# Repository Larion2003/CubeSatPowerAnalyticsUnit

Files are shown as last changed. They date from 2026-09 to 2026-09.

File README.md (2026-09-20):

# TiSAT CubeSat - Power Analytics Unit 
 
This repository contains the design and development files for the Power Analytics Unit of the **TiSAT CubeSat** project. The primary objective is to monitor and analyze the power consumption of various sensors integrated into the satellite. 
 
## Project Overview 
The core of this project is a custom-designed power measurement circuit. It utilizes a **shunt resistor** to measure minute currents and voltage levels across specific circuit branches, enabling precise power calculation.  
 
Since the satellite is equipped with **solar panels** for battery charging, the power management logic accounts for both energy harvesting and consumption cycles to ensure balanced power distribution. 
 
## Current Progress
- [x] **Circuit Design:** Completed the schematic and PCB layout using **KiCad**.
- [x] **Component Selection:** Selected specialized ICs for precision current sensing and power management.
- [x] **Manufacturing & Assembly:** The custom PCB has been fully manufactured, and all SMD and through-hole components (including critical high-precision IC packages) have been successfully soldered and assembled.
- [x] **Firmware Communication Loop:** Successfully established a low-level, non-blocking hardware communication interface between the STM32 MCU and a Raspberry Pi Pico W using UART with inverted polarity.
- [x] **Ping-Pong Verification:** Confirmed working end-to-end UART communication on the shared single-wire bus — the STM32 now reliably replies `pong\n` to every `ping\n` sent by the Raspberry Pi Pico W, verifying the physical link between the two microcontrollers.
- [x] **Shunt Resistor Calibration:** Performed a 4-point (Kelvin) measurement to precisely determine the shunt resistor's true value (50 mΩ).
- [x] **TiSAT Protocol Implementation:** Replaced the raw ping-pong test with the full, checksum-validated TiSAT frame protocol (`$`/`#` direction, 3-character module ID, payload, checksum, terminator), matching the shared master-side specification used across the TiSAT project's other modules.
- [x] **ADC-Based Power Measurement:** Implemented calibrated ADC sampling of the shunt voltage — using the internal VREFINT reference to compensate for real VDDA deviation — converting the INA199 current-sense amplifier output into live current, voltage and power readings, delivered over the `GETDATA` command.
- [ ] **End-to-End Master Integration:** Validate live communication between this module and the actual TiSAT master OBC (currently verified against a Raspberry Pi Pico W test harness simulating the master).

## Technical Roadmap & Development 
The software architecture focuses on the low-level firmware development for the onboard microcontroller and the receiving subsystem: 
1. **Custom HAL (Hardware Abstraction Layer):** Writing bare-metal foundational drivers from scratch to manage MCU peripherals (RCC, GPIO, ADC, USART). 
2. **Interrupt-Driven Transmission:** Implemented an optimized background data streaming pipeline in **C++** using the `TXE` interrupt vector. This allows the STM32 to transmit real-time sensor metrics periodically every $X$ seconds without blocking main CPU execution.
3. **Subsystem Receiver:** Developed a non-blocking CircuitPython-based listener on the Raspberry Pi Pico W to process telemetry frames while maintaining a constant diagnostic heartbeat LED toggle.
4. **Bidirectional Half-Duplex Communication:** The immediate next phase is to extend the current single-wire bus setup to full **Half-Duplex bidirectional mode**. The system will be upgraded so that the Pico can parse the incoming `$TM` telemetry packages and safely reply back to the STM32 over the shared Open-Drain channel.
5. **Analytics & Logging:** Developing the final data processing logic to log and analyze historical sensor power consumption. 
 
## About the Author 
This project is being developed as part of my **undergraduate thesis** at the **University of Szeged (SZTE)**, under the guidance of my mentor.  
 
It serves as a practical application of my ongoing studies in **C, C++, and Assembly**. This mission allows me to bridge the gap between hardware design and low-level software engineering while contributing to the **TiSAT satellite mission**. 
 
--- 
*Thank you for visiting this repository!*

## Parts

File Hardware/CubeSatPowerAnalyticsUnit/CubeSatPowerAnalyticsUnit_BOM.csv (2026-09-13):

"Reference,""Qty"",""Value"",""DNP"",""Exclude from BOM"",""Exclude from Board"",""Footprint"",""Datasheet"",""Purchase"",""LCSC"""
"C1,C2,C3,""3"",""100 nF"","""",""Excluded from BOM"",""Excluded from board"",""Capacitor_SMD:C_0805_2012Metric_Pad1.18x1.45mm_HandSolder"",""~"","""",""C49678"""
"D1,""1"",""BAT43W-V"","""",""Excluded from BOM"",""Excluded from board"",""Diode_SMD:D_SOD-123"",""http://www.vishay.com/docs/85660/bat42.pdf"","""",""C188548"""
"INA1,""1"",""INA199xxDCK"","""","""","""",""Package_TO_SOT_SMD:SOT-363_SC-70-6"",""http://www.ti.com/lit/ds/symlink/ina199.pdf"","""",""C59135"""
"J1,""1"",""Conn_01x05_Pin"","""",""Excluded from BOM"",""Excluded from board"",""Connector_PinHeader_2.54mm:PinHeader_1x05_P2.54mm_Horizontal"",""~"","""",""C2883689"""
"MCU1,""1"",""STM32L431KCUx"","""","""","""",""Package_DFN_QFN:QFN-32-1EP_5x5mm_P0.5mm_EP3.45x3.45mm"",""https://www.st.com/resource/en/datasheet/stm32l431kc.pdf"","""",""C1341298"""
"Q1,""1"",""2N7002"","""","""","""",""Package_TO_SOT_SMD:SOT-23"",""https://www.onsemi.com/pub/Collateral/NDS7002A-D.PDF"","""",""C332103"""
"R1,""1"",""0.05 Ohm"","""","""","""",""Resistor_SMD:R_0805_2012Metric_Pad1.20x1.40mm_HandSolder"",""~"","""",""C49164908"""
"R2,""1"",""1K Ohm"","""",""Excluded from BOM"",""Excluded from board"",""Resistor_SMD:R_0805_2012Metric_Pad1.20x1.40mm_HandSolder"",""~"","""",""C2889523"""
"R3,""1"",""10K Ohm"","""",""Excluded from BOM"",""Excluded from board"",""Resistor_SMD:R_0805_2012Metric_Pad1.20x1.40mm_HandSolder"",""~"","""",""C17414"""
"T1,""1"",""V_In (3,3V)"","""",""Excluded from BOM"",""Excluded from board"",""TestPoint:TestPoint_Pad_3.0x3.0mm"",""~"","""","""""
"T2,""1"",""V_Out"","""",""Excluded from BOM"",""Excluded from board"",""TestPoint:TestPoint_Pad_3.0x3.0mm"",""~"","""","""""
"T3,""1"",""GND"","""",""Excluded from BOM"",""Excluded from board"",""TestPoint:TestPoint_Pad_3.0x3.0mm"",""~"","""","""""
"T4,""1"",""UART"","""",""Excluded from BOM"",""Excluded from board"",""TestPoint:TestPoint_Pad_3.0x3.0mm"",""~"","""","""""

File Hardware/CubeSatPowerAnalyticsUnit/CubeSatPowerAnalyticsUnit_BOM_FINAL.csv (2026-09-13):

Designator | Value | Footprint | LCSC
INA1 | INA199xxDCK | SOT-363_SC-70-6 | C59135
MCU1 | STM32L431KCUx | QFN-32-1EP_5x5mm_P0.5mm_EP3.45x3.45mm | C1341298
Q1 | 2N7002 | SOT-23 | C332103

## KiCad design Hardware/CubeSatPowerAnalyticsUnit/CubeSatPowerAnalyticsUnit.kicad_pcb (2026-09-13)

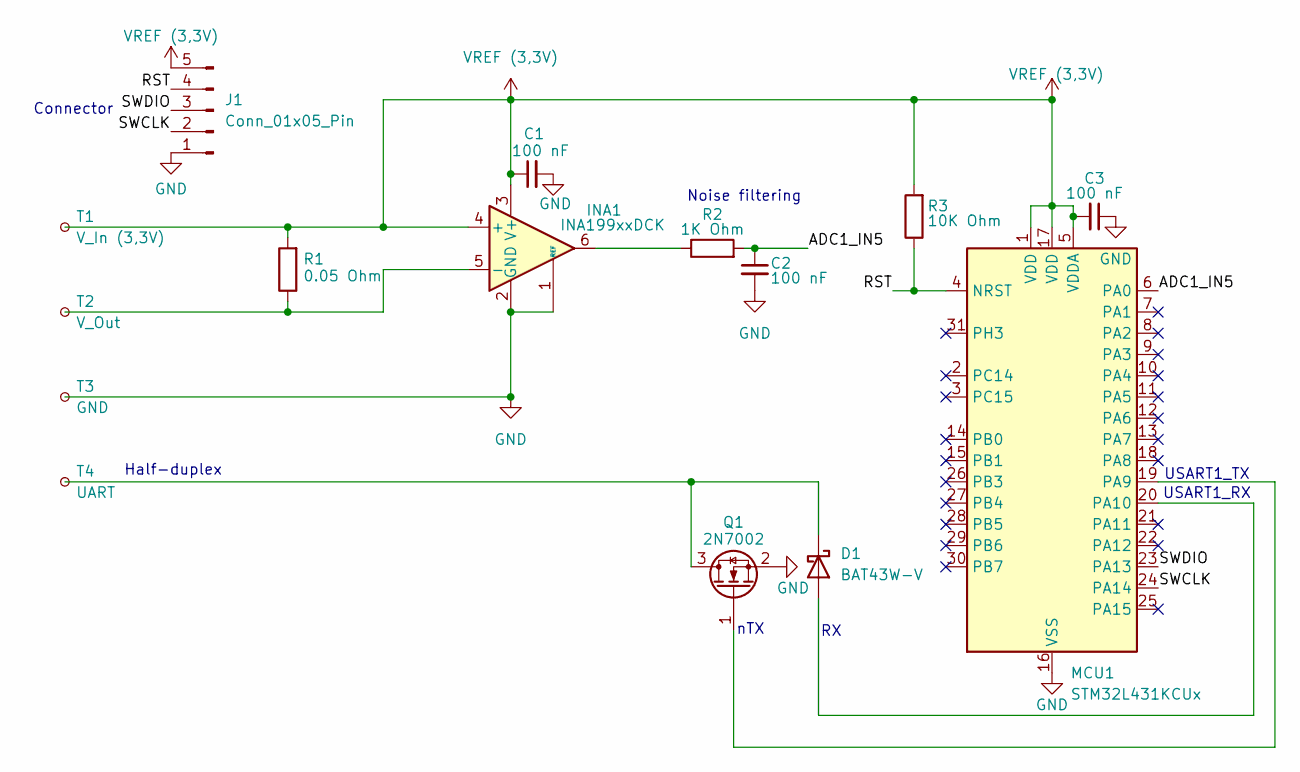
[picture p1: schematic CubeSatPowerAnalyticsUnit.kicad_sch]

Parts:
C1, C2, C3: 100 nF; C_0805_2012Metric_Pad1.18x1.45mm_HandSolder; LCSC C49678
D1: BAT43W-V; D_SOD-323_HandSoldering; LCSC C188548
INA1: INA199xxDCK; SOT-363_SC-70-6; LCSC C59135
J1: Conn_01x05_Pin; PinHeader_1x05_P2.54mm_Horizontal; LCSC C2883689
MCU1: STM32L431KCUx; QFN-32-1EP_5x5mm_P0.5mm_EP3.45x3.45mm; LCSC C1341298
Q1: 2N7002; SOT-23; LCSC C332103
R1: 0.05 Ohm; R_0805_2012Metric_Pad1.20x1.40mm_HandSolder; LCSC C49164908
R2: 1K Ohm; R_0805_2012Metric_Pad1.20x1.40mm_HandSolder; LCSC C2889523
R3: 10K Ohm; R_0805_2012Metric_Pad1.20x1.40mm_HandSolder; LCSC C17414
T1: V_In (3,3V); TestPoint_Pad_3.0x3.0mm
T2: V_Out; TestPoint_Pad_3.0x3.0mm
T3: GND; TestPoint_Pad_3.0x3.0mm
T4: UART; TestPoint_Pad_3.0x3.0mm

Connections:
/ADC1_IN5: C2.1, MCU1.6 (PA0), R2.2
/RST: J1.4, MCU1.4 (NRST), R3.1
/SWCLK: J1.2, MCU1.24 (PA14)
/SWDIO: J1.3, MCU1.23 (PA13)
GND: C1.2, C2.2, C3.1, INA1.1 (REF), INA1.2 (GND), J1.1, MCU1.16 (VSS), MCU1.32 (VSS), MCU1.33 (VSS), Q1.2 (S), T3.1
unnamed: D1.2 (A), MCU1.20 (PA10)
unnamed: D1.1 (K), Q1.3 (D), T4.1
unnamed: INA1.5 (-), R1.1, T2.1
unnamed: INA1.6, R2.1
unnamed: MCU1.19 (PA9), Q1.1 (G)
VREF (3,3V): C1.1, C3.2, INA1.3 (V+), INA1.4 (+), J1.5, MCU1.1 (VDD), MCU1.5 (VDDA), MCU1.17 (VDD), R1.2, R3.2, T1.1

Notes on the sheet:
Noise filtering
Half-duplex
USART1_RX
nTX
USART1_TX
Connector

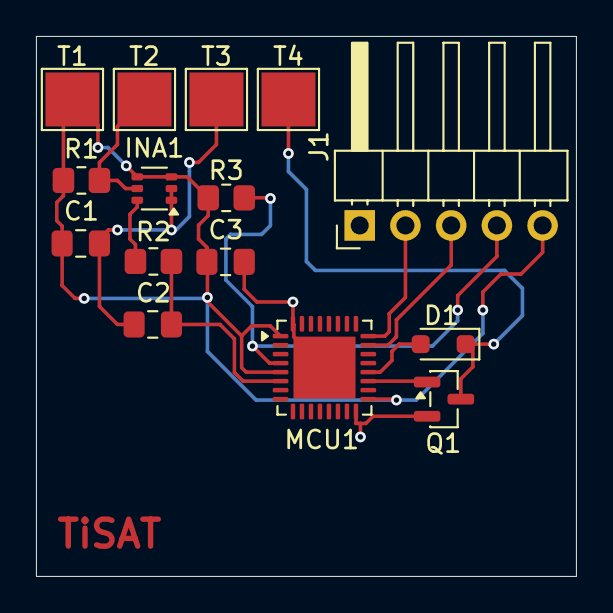
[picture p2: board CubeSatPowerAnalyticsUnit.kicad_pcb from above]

Board: 2 copper layers, 30.0 x 30.0 mm, 15 parts (0 on the bottom side), 11 nets.

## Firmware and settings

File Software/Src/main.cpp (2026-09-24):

#include "main.hpp"
#include "stm32l431xx.h"
#include <cstddef>
#include <cstdint>
#include <cstdio>
#include <cstring>

// ==================================================================================================
// PWR MODULE — TiSAT-compatible slave communication protocol
// ==================================================================================================
// Frame format (max 64 bytes total), matching the shared TiSAT protocol:
//   [direction: 1 char] [module: 3 chars] [payload] [%] [checksum: 2 hex chars] [\r\n]
//
//   '$' -> command sent by the master, addressed to a module
//   '#' -> reply sent by a module back to the master
//
// Checksum: 8-bit sum (wrapping at 256) of every byte from the direction char
// up to and including '%', written as 2 uppercase hex digits.
//
// Commands handled by this module:
//   "ping"    -> "pong"                  : liveness check
//   "GETDATA" -> "I:..,U:..,W:.."        : current, voltage and power readout
// ==================================================================================================

// Blocks until a byte has been fully received (RXNE flag set), then reads
// and returns it. Reading RDR also clears the RXNE flag.
char uart_getc()
{
    while (!(USART1->ISR & USART_ISR_RXNE)) {}
    return USART1->RDR;
}

// Blocks until the transmit data register is empty (TXE flag set), then
// loads the next byte into TDR to start shifting it out on the line.
void uart_putc(char c)
{
    while (!(USART1->ISR & USART_ISR_TXE)) {}

    USART1->TDR = static_cast<uint8_t>(c);
}

// Sends a null-terminated string one byte at a time via uart_putc(),
// stopping at the terminating '\0'.
void uart_puts(const char* str)
{
    while (*str) {
        uart_putc(*str++);
    }
}

// Blocks until the last byte has been fully shifted out onto the line
// (TC flag set), meaning transmission is physically complete — not just
// that TDR is empty (TXE), but that the stop bit has also left the pin.
void wait_free_bus(){while (!(USART1->ISR & USART_ISR_TC)) {}}

namespace {

    // -------------------------------- CONSTANTS --------------------------------

    constexpr const size_t   ADC1_CHANNEL     = 5;          // PA0 current shunt input channel
    constexpr const uint32_t ADC_CH0_VREFINT  = 0;          // Internal reference voltage channel
    constexpr const float    SHUNT_RESISTOR   = 0.0522865f; // 52.2865 mOhm shunt resistance, 4-point measured
    constexpr const float    INA199_GAIN      = 50.0f;      // INA199A1 current-sense amplifier gain (V/V)
    constexpr const float    ADC_FULL_SCALE   = 4095.0f;    // 12-bit ADC: max raw reading (2^12 - 1)
    constexpr const float    VREFINT_CAL_VDDA = 3.0f;       // VDDA at which VREFINT_CAL was factory-measured
    constexpr const size_t   FREQ_SYS         = 4000000;    // 4 MHz MSI system clock
    constexpr const size_t   TARGET_BAUDRATE  = 9600;
    constexpr const uint8_t  MSG_BUFFER_SIZE  = 64;          // Max frame length, matches the protocol spec

    // Factory calibration address for internal voltage reference (1.212V typical)
    const uint16_t* VREF_INT_CAL_ADDR = reinterpret_cast<uint16_t*>(0x1FFF75AA);

    // Baud Rate Generator Register Value: 4,000,000 / 9600 = 416
    constexpr size_t USART1_BRR = FREQ_SYS / TARGET_BAUDRATE;

    // -------------------------------- PROTOCOL IDENTITY --------------------------------

    constexpr const char MODULE_ID[3]    = {'P', 'W', 'R'};
    constexpr const char DIR_FROM_MASTER = '$';   // Command addressed to this module
    constexpr const char DIR_TO_MASTER   = '#';   // Reply sent back to the master

    constexpr const char* CMD_PING     = "ping";
    constexpr const char* CMD_GET_DATA = "GETDATA";
    constexpr const char* RESP_PONG    = "pong";

    // -------------------------------- TELEMETRY CACHE --------------------------------
    // Refreshed by update_measurements() right before every GETDATA reply.

    volatile float shunt_voltage = 0.0f;   // Bus voltage (VDDA), in volts
    volatile float shunt_current = 0.0f;   // Current through the shunt, in amps
    volatile float shunt_power   = 0.0f;   // shunt_voltage * shunt_current, in watts

    // -------------------------------- FRAME BUFFERS --------------------------------

    char    rx_buffer[MSG_BUFFER_SIZE];   // Accumulates one incoming frame, byte by byte
    uint8_t rx_index = 0;

    char    tx_buffer[MSG_BUFFER_SIZE];   // Holds one outgoing frame while it is built and sent

    // -------------------------------- ADC HELPERS --------------------------------

    // Busy-waits for approximately 'us' microseconds using the DWT cycle counter
    // that SystemInit() already started. Only used for the short ADC voltage
    // regulator startup delay, which is too brief to justify a hardware timer.
    void delay_us(uint32_t us) {
        const uint32_t start  = DWT->CYCCNT;
        const uint32_t cycles = us * (FREQ_SYS / 1000000);
        while (DWT->CYCCNT - start < cycles) {}
    }

    // Brings up ADC1: exits deep-power-down, enables its internal voltage
    // regulator, calibrates it, and switches it on. Runs once, before any
    // conversion is requested. Follows the power-up sequence from the
    // reference manual's ADC chapter.
    //
    // PA0 itself needs no GPIO setup: every regular pin resets into analog
    // mode by default, which is exactly the mode the ADC input needs.
    void adc_init() {
        ADC1->CR &= ~ADC_CR_DEEPPWD;     // Wake the ADC up from deep-power-down (its reset state)
        ADC1->CR |= ADC_CR_ADVREGEN;     // Enable the ADC's internal voltage regulator
        delay_us(20);                     // T_ADCVREG_STUP: regulator startup time

        // Clocks ADC1 directly from HCLK with no prescaler — the simplest option,
        // valid because this project runs the default, undivided 4 MHz MSI clock.
        ADC1_COMMON->CCR = (ADC1_COMMON->CCR & ~ADC_CCR_CKMODE) | ADC_CCR_CKMODE_0;

        // Connects the internal reference voltage to the ADC so it can be read
        // like any other channel (channel 0, see ADC_CH0_VREFINT above).
        ADC1_COMMON->CCR |= ADC_CCR_VREFEN;

        ADC1->CR |= ADC_CR_ADCAL;             // Start single-ended calibration
        while (ADC1->CR & ADC_CR_ADCAL) {}    // Wait until calibration completes

        // Longest available sample time (640.5 ADC clock cycles) for both the
        // shunt channel and VREFINT: accuracy matters far more here than speed,
        // and the 1K filter resistor (R2) ahead of the shunt channel needs
        // extra settling time to charge the ADC's internal sampling capacitor.
        ADC1->SMPR1 |= ADC_SMPR1_SMP0 | ADC_SMPR1_SMP5;

        ADC1->CR |= ADC_CR_ADEN;                  // Enable the ADC
        while (!(ADC1->ISR & ADC_ISR_ADRDY)) {}   // Wait until it reports ready
    }

    // Runs one single-channel conversion and returns the raw 12-bit result.
    uint16_t adc_read_channel(uint32_t channel) {
        ADC1->SQR1 = (channel << ADC_SQR1_SQ1_Pos);  // 1-entry sequence: convert only 'channel'
        ADC1->CR |= ADC_CR_ADSTART;                   // Start the conversion

        while (!(ADC1->ISR & ADC_ISR_EOC)) {}         // Wait for "end of conversion"
        return static_cast<uint16_t>(ADC1->DR);       // Reading DR also clears EOC
    }

    // Refreshes shunt_voltage/shunt_current/shunt_power from a fresh pair of
    // ADC readings.
    //
    // VDDA (the analog supply) is not assumed to be exactly 3.3V: it is derived
    // from the internal reference channel against its factory calibration
    // value, which is far more accurate than trusting the nominal supply
    // voltage. Since this board's own 3.3V rail (VDDA) is the same rail the
    // shunt monitors (see T1/V_In on the schematic), that calibrated VDDA
    // doubles as the measured bus voltage ("U").
    void update_measurements() {
        const uint16_t vrefint_raw = adc_read_channel(ADC_CH0_VREFINT);
        const float vdda = VREFINT_CAL_VDDA *
            (static_cast<float>(*VREF_INT_CAL_ADDR) / static_cast<float>(vrefint_raw));

        const uint16_t shunt_raw = adc_read_channel(ADC1_CHANNEL);
        const float shunt_adc_voltage = (static_cast<float>(shunt_raw) / ADC_FULL_SCALE) * vdda;

        // The INA199 output is the shunt's own voltage drop multiplied by its
        // fixed gain; dividing it back out recovers the drop, and Ohm's law
        // then turns that into the current flowing through the shunt.
        const float shunt_drop_voltage = shunt_adc_voltage / INA199_GAIN;

        shunt_voltage = vdda;
        shunt_current = shunt_drop_voltage / SHUNT_RESISTOR;
        shunt_power   = shunt_voltage * shunt_current;
    }

    // -------------------------------- PROTOCOL HELPERS --------------------------------

    // Sums every byte from index 0 up to and including index 'percent_index' (the '%' byte),
    // wrapping at 256 via uint8_t overflow. Matches the shared protocol's checksum rule.
    uint8_t calc_checksum(const char* frame, size_t percent_index) {
        uint8_t sum = 0;
        for (size_t i = 0; i <= percent_index; i++) {
            sum += static_cast<uint8_t>(frame[i]);
        }
        return sum;
    }

    // Converts a 4-bit value (0-15) into its uppercase ASCII hex digit.
    // Used to encode the 1-byte checksum as 2 printable characters.
    char nibble_to_hex(uint8_t n) {
        const char LUT[] = "0123456789ABCDEF";
        return LUT[n & 0x0F];
    }

    // Converts a single ASCII hex digit ('0'-'9', 'A'-'F', 'a'-'f') back into
    // its 4-bit value. Used to decode the checksum received from the master.
    uint8_t hex_to_nibble(char c) {
        if (c >= '0' && c <= '9') return static_cast<uint8_t>(c - '0');
        if (c >= 'A' && c <= 'F') return static_cast<uint8_t>(c - 'A' + 10);
        if (c >= 'a' && c <= 'f') return static_cast<uint8_t>(c - 'a' + 10);
        return 0;
    }

    // Returns the index of the payload-terminating '%', or -1 if not found in [0, len).
    int find_percent(const char* buf, size_t len) {
        for (size_t i = 0; i < len; i++) {
            if (buf[i] == '%') return static_cast<int>(i);
        }
        return -1;
    }

    // Builds a full reply frame ('#PWR' + payload + '%' + checksum + "\r\n") and transmits it.
    //
    // On this single-wire bus, every transmitted byte is reflected back onto RX, so RE is
    // disabled for the duration of the send and only re-enabled once the line is confirmed
    // free (TC flag) and any leftover RXNE has been flushed. This is the same technique that
    // already proved stable for the plain "pong\n" reply.
    void send_frame(const char* payload) {
        size_t idx = 0;

        tx_buffer[idx++] = DIR_TO_MASTER;
        tx_buffer[idx++] = MODULE_ID[0];
        tx_buffer[idx++] = MODULE_ID[1];
        tx_buffer[idx++] = MODULE_ID[2];

        for (const char* p = payload; *p != '\0' && idx < (MSG_BUFFER_SIZE - 5); p++) {
            tx_buffer[idx++] = *p;
        }

        const size_t percent_index = idx;
        tx_buffer[idx++] = '%';

        const uint8_t chk = calc_checksum(tx_buffer, percent_index);
        tx_buffer[idx++] = nibble_to_hex(chk >> 4);
        tx_buffer[idx++] = nibble_to_hex(chk & 0x0F);

        tx_buffer[idx++] = '\r';
        tx_buffer[idx++] = '\n';

        USART1->CR1 &= ~USART_CR1_RE;   // Receiver off: keep our own echo out of RDR

        for (size_t i = 0; i < idx; i++) {
            uart_putc(tx_buffer[i]);
        }
        wait_free_bus();                 // Block until the last byte has fully left the line

        (void)USART1->RDR;               // Clear any leftover RXNE flag before RX is re-enabled

        USART1->CR1 |= USART_CR1_RE;    // Receiver back on: ready for the next real command
    }

    // Validates and dispatches one complete, "\n"-terminated frame from rx_buffer.
    void process_frame(const char* buf, size_t len) {
        const int pct = find_percent(buf, len);

        // A valid frame needs at least a direction char, 3 module chars, and a '%',
        // plus room for the 2 checksum digits after it.
        if (pct < 4 || static_cast<size_t>(pct) + 2 >= len) {
            return;
        }

        if (buf[0] != DIR_FROM_MASTER) {
            return;   // Not a command addressed to a module (e.g. our own echo slipping through)
        }

        const uint8_t rx_chk = static_cast<uint8_t>(
            (hex_to_nibble(buf[pct + 1]) << 4) | hex_to_nibble(buf[pct + 2]));
        if (rx_chk != calc_checksum(buf, static_cast<size_t>(pct))) {
            return;   // Corrupted frame, silently dropped
        }

        const bool for_us = (buf[1] == MODULE_ID[0]) &&
                             (buf[2] == MODULE_ID[1]) &&
                             (buf[3] == MODULE_ID[2]);
        if (!for_us) {
            return;   // Addressed to a different module
        }

        char payload[MSG_BUFFER_SIZE];
        const size_t payload_len = static_cast<size_t>(pct) - 4;
        memcpy(payload, &buf[4], payload_len);
        payload[payload_len] = '\0';

        if (strcmp(payload, CMD_PING) == 0) {
            send_frame(RESP_PONG);

        } else if (strcmp(payload, CMD_GET_DATA) == 0) {
            update_measurements();   // Take a fresh reading right before replying

            char data_payload[MSG_BUFFER_SIZE];
            snprintf(data_payload, sizeof(data_payload), "I:%.4f mA,U:%.4f mV,W:%.4f mW",
                      static_cast<double>(shunt_current * 1000.0f),
                      static_cast<double>(shunt_voltage * 1000.0f),
                      static_cast<double>(shunt_power * 1000.0f));
            send_frame(data_payload);
        }
    }

} // anonymous namespace

// ==================================================================================================
// SystemInit — Peripherals Initialization Routine
// ==================================================================================================
extern "C" void SystemInit() {

    // Enables the DWT (Data Watchpoint and Trace) cycle counter.
    // CYCCNT increments once per core clock cycle and is used as a
    // free-running timer for cycle-accurate delay measurements.
    CoreDebug->DEMCR |= CoreDebug_DEMCR_TRCENA_Msk;
    DWT->CYCCNT = 0;
    DWT->CTRL  |= DWT_CTRL_CYCCNTENA_Msk;

    // Enables the peripheral clocks required by this module.
    // A peripheral's registers cannot be accessed until its clock is enabled.
    RCC->AHB2ENR |= RCC_AHB2ENR_GPIOAEN;   // GPIOA clock
    RCC->APB2ENR |= RCC_APB2ENR_USART1EN;  // USART1 clock
    RCC->AHB2ENR |= RCC_AHB2ENR_ADCEN;     // ADC1 clock

    // ==========================================================================
    // USART1 Configuration — Half-Duplex Single-Wire (9600 Baud)
    // Pin: PA9 (Single shared TX/RX line)
    // ==========================================================================

    // Sets PA9 (USART1_TX) and PA10 (USART1_RX) to Alternate Function mode.
    // PA13/PA14 (SWDIO/SWCLK) are intentionally left untouched here — after
    // reset, they are already in Alternate Function mode by default, so the
    // debugger stays connected without any firmware configuration needed.
    GPIOA->MODER &= ~(GPIO_MODER_MODE9  | GPIO_MODER_MODE10);
    GPIOA->MODER |=  (GPIO_MODER_MODE9_1 | GPIO_MODER_MODE10_1);

    // Selects AF7 (USART1) as the alternate function routed to PA9 and PA10.
    GPIOA->AFR[1] &= ~(GPIO_AFRH_AFSEL9 | GPIO_AFRH_AFSEL10);
    GPIOA->AFR[1] |=  (7u << GPIO_AFRH_AFSEL9_Pos) |
    (7u << GPIO_AFRH_AFSEL10_Pos);

    // Baud rate register: USART1_BRR = system clock / target baud rate.
    // At a 4 MHz system clock this yields 9600 baud.
    USART1->BRR = USART1_BRR;

    // Inverts the TX line logic level. The board routes PA9 through an external
    // hardware inverter, so this compensates for it and restores a
    // non-inverted signal on the physical bus.
    USART1->CR2 |= USART_CR2_TXINV;

    // Disables the overrun error flag (ORE). Without this, an unread byte
    // being overwritten by a new one would block further reception until
    // the flag is cleared in software.
    USART1->CR3 = USART_CR3_OVRDIS;

    // Enables the transmitter (TE), the receiver (RE), and the USART
    // peripheral itself (UE). Without UE, none of the above settings take effect.
    USART1->CR1 |= USART_CR1_TE | USART_CR1_RE | USART_CR1_UE;
}

// ==================================================================================================
// Main Execution Loop
// ==================================================================================================
// Continuously reads one byte at a time from the master and accumulates it into rx_buffer.
// Once a full line ('\n') has arrived, the buffered bytes make up one complete frame, which is
// handed off to process_frame() for validation and dispatch. rx_index is then reset, ready to
// accumulate the next frame.
int main() {

    adc_init();

    char c;
    while (true)
    {
        c = uart_getc();

        // Safety: a frame that somehow exceeds the buffer without a terminator
        // (e.g. line noise) is discarded so the parser can resync on the next one.
        if (rx_index >= MSG_BUFFER_SIZE) {
            rx_index = 0;
        }

        rx_buffer[rx_index++] = c;

        if (c == '\n')
        {
            process_frame(rx_buffer, rx_index);
            rx_index = 0;
        }
    }

    return 0;
}

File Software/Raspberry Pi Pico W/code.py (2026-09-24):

# Test master for the PWR module: sends ping/GETDATA over the shared
# single-wire UART bus and logs both sides of the conversation.

import board
import busio
import digitalio
import time

uart = busio.UART(board.GP0, board.GP1, baudrate=9600)

led = digitalio.DigitalInOut(board.LED)
led.direction = digitalio.Direction.OUTPUT

MODULE = "PWR"

MASTER_LABEL = "Raspberry Pi Pico W (Master)"
SLAVE_LABEL  = "STM32L431KC - PWR module (Slave)"
LABEL_WIDTH  = max(len(MASTER_LABEL), len(SLAVE_LABEL))

# Lines up the arrow in the same column no matter how long the label is.
def log(label, message):
    print(f"{label:<{LABEL_WIDTH}} -> {message}")

# Same checksum rule as the STM32 side: sum of 'body' (already has the
# trailing '%'), wrapping at 256.
def calc_checksum(body):
    checksum = 0
    for ch in body:
        checksum = (checksum + ord(ch)) & 0xFF
    return checksum

# "$" + module + payload + "%" + 2 hex checksum digits + "\r\n"
def build_frame(payload):
    body = "$" + MODULE + payload + "%"
    checksum = calc_checksum(body)
    return f"{body}{checksum:02X}\r\n"

# Sends one command frame and returns the slave's reply line.
def send_command(payload):
    log(MASTER_LABEL, payload)

    frame = build_frame(payload)
    uart.write(frame.encode("ascii"))

    # We hear our own bytes back on this shared bus, so the first line is our own echo.
    echo = uart.readline()

    # The slave's real reply follows next.
    reply = uart.readline()
    return reply

# Pulls the payload out of a "#PWR...%.." reply, or None if it's missing/malformed.
def extract_payload(line):
    if not line:
        return None
    try:
        text = line.decode().strip()
    except UnicodeError:
        return None   # bus noise, skip this line
    if len(text) < 5 or text[0] != "#":
        return None
    percent_index = text.find("%")
    if percent_index < 4:
        return None
    return text[4:percent_index]

# Alternates ping/GETDATA once a second, blinking the onboard LED as a heartbeat.
while True:
    reply = send_command("ping")
    log(SLAVE_LABEL, extract_payload(reply))
    led.value = not led.value
    time.sleep(0.5)

    reply = send_command("GETDATA")
    log(SLAVE_LABEL, extract_payload(reply))
    led.value = not led.value
    time.sleep(0.5)

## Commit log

2026-02-23 Initial commit - KiCad project start
    [CubeSatPowerAnalyticsUnit.kicad_pcb, CubeSatPowerAnalyticsUnit.kicad_sch]
2026-02-25 Start PCB layout and initial routing.
    [CubeSatPowerAnalyticsUnit.kicad_pcb]
2026-02-26 Initial commit - KiCad project v1.0
2026-02-26 Initial commit - KiCad project v1.1
2026-03-02 Initial commit - KiCad project v1.2
    [CubeSatPowerAnalyticsUnit.kicad_pcb, CubeSatPowerAnalyticsUnit.kicad_sch]
2026-03-05 Update PCB design - KiCad project v1.3
    [CubeSatPowerAnalyticsUnit.kicad_pcb, CubeSatPowerAnalyticsUnit.kicad_sch]
2026-03-22 Generate fabrication files - KiCad project v1.4
    [CubeSatPowerAnalyticsUnit.kicad_sch, CubeSatPowerAnalyticsUnit_BOM.csv, CubeSatPowerAnalyticsUnit_BOM_FINAL.csv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]
2026-03-22 Modify various footprints - KiCad project v1.5
    [CubeSatPowerAnalyticsUnit.kicad_pcb, CubeSatPowerAnalyticsUnit.kicad_sch]
2026-03-23 Fixing some issues - KiCad project v1.6
    [CubeSatPowerAnalyticsUnit.kicad_pcb]
2026-04-16 Refactor project structure: separated hardware and software (History restored)
    [CubeSatPowerAnalyticsUnit.kicad_pcb, CubeSatPowerAnalyticsUnit.kicad_sch, CubeSatPowerAnalyticsUnit_BOM.csv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]
2026-07-09 Hardware Abstraction Layer: v1.3 - Implement interrupt-driven UART from STM32 to Raspberry Pi.
2026-08-24 Hardware Abstraction Layer: v1.4 - create TiSAT Frame Structure (beta version)
2026-09-13 Firmware logic reset: Add ping-pong logic
    [CubeSatPowerAnalyticsUnit.kicad_pcb, CubeSatPowerAnalyticsUnit.kicad_sch, CubeSatPowerAnalyticsUnit_BOM.csv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]
2026-09-20 Implement TiSAT protocol: Add framed ping/pong and GETDATA telemetry request
2026-09-20 Implement calibrated ADC-based voltage, current and power measurement
2026-09-24 Update shunt value to measured resistance, add Pico heartbeat LED.
2026-10-07 Add linear-regression current calibration with 64x ADC oversampling.
